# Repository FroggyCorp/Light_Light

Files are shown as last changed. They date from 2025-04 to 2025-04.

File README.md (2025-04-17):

# Light Light
It's a small PCB game with actually 2 games :

https://www.youtube.com/video/Cth2Q4qN7tQ/

https://www.youtube.com/video/z0U1Xu2ibLQ/

## The game

### How it work
Button 9 disable sound (horrible, i know)
Button 1 & 2 start game 1 or 2
All Button Player 1 & 2 at same time at the beggining reset highscore (little bit hard)

### Configuration
In light_light_func.h duree_jeu change the timeout of game1 2 = 20s
You can also change how many led will light at same time on game 1 with Jeu1_nombre_led_joueur_actif

### Game 1
You will have 4 LED, press button with led on as fast as you can until timeout of the game.

### Game 2
The program will add one led every x secondes, going faster and faster. It end when all the led are on for the two players.

## Game Board

Actually there is only dev board, which don't change so much. You can remove external connector to gain some place and make a smaller PCB.
It use an Attiny1604 & HT16K33A as it was the cheapest price and easy to use. Version with 75HC595 & 74HC595 may be a little bit cheaper but more difficult to make.
For Attiny1604, all reference on how to use it are[here]([https://pages.github.com/](https://github.com/SpenceKonde/AVR-Guidance/blob/master/UPDI/jtag2updi.md)) for UDPI & [here](https://github.com/SpenceKonde/megaTinyCore)
Thanks to [SpenceKonde](https://github.com/SpenceKonde) for his huge great work.

### Get notice
I use v1.1, v1.2 have some change and should work without problem.

### Information about the board
The board have 2 footprint for microphone, you need to get a passive one.
There are 2 foorprint for button + LED. One is cheap with standard 6x6mm tactil switch and 5730 LED, the other one use more expensive set with tactil switch & led in same package. You can take with [cap](https://www.lcsc.com/product-detail/Tactile-Switches_ROCPU-Switches-TPB01-101L1W_C2762125.html) or without and take that type of [cap] (https://www.lcsc.com/product-detail/Switch-Accessories-Caps_Khon-SC804AF1_C45359438.html). Be aware that some button + LED have cathode/anode at different position which will not work.
With 5730 LED, i recommend 5Kohm for R77 to R88 and 330ohm for the others.
You could also change the R for green LED.

### v1.2 :
- Correction Bug with Led J2 6-7-8-9
- Mutualising R for button
- Double footprint for microphone
- Change mounting hole
- Smaller PCB
- Add 5x220Ohm resistor to trick external battery cut off

## Small box

You can find .stl and FreeCad file inside FreeCad dir, as well as the PCB, i didn't try that version.

# Licence
Copyright (c) 2025 Froggy / FroggyCorp.

Do what you want with it until it's not money.

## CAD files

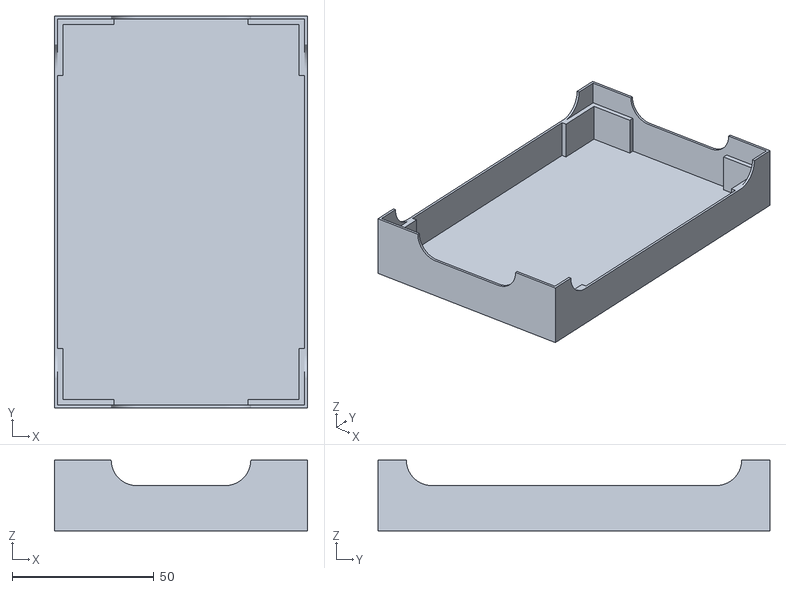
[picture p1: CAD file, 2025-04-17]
FreeCAD/Top - Dev Board v1.2.stl
89.2 x 138.2 x 25.0

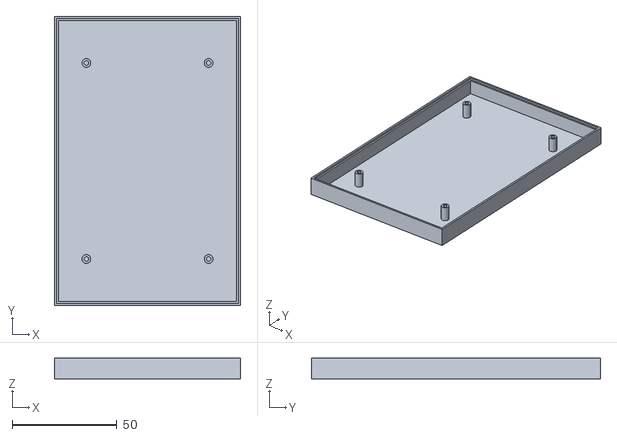
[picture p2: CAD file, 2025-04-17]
FreeCAD/Bottom - Dev Board v1.2.stl
89.0 x 138.0 x 10.0

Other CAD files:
FreeCAD/Boitier - Dev Board v1.2.FCStd

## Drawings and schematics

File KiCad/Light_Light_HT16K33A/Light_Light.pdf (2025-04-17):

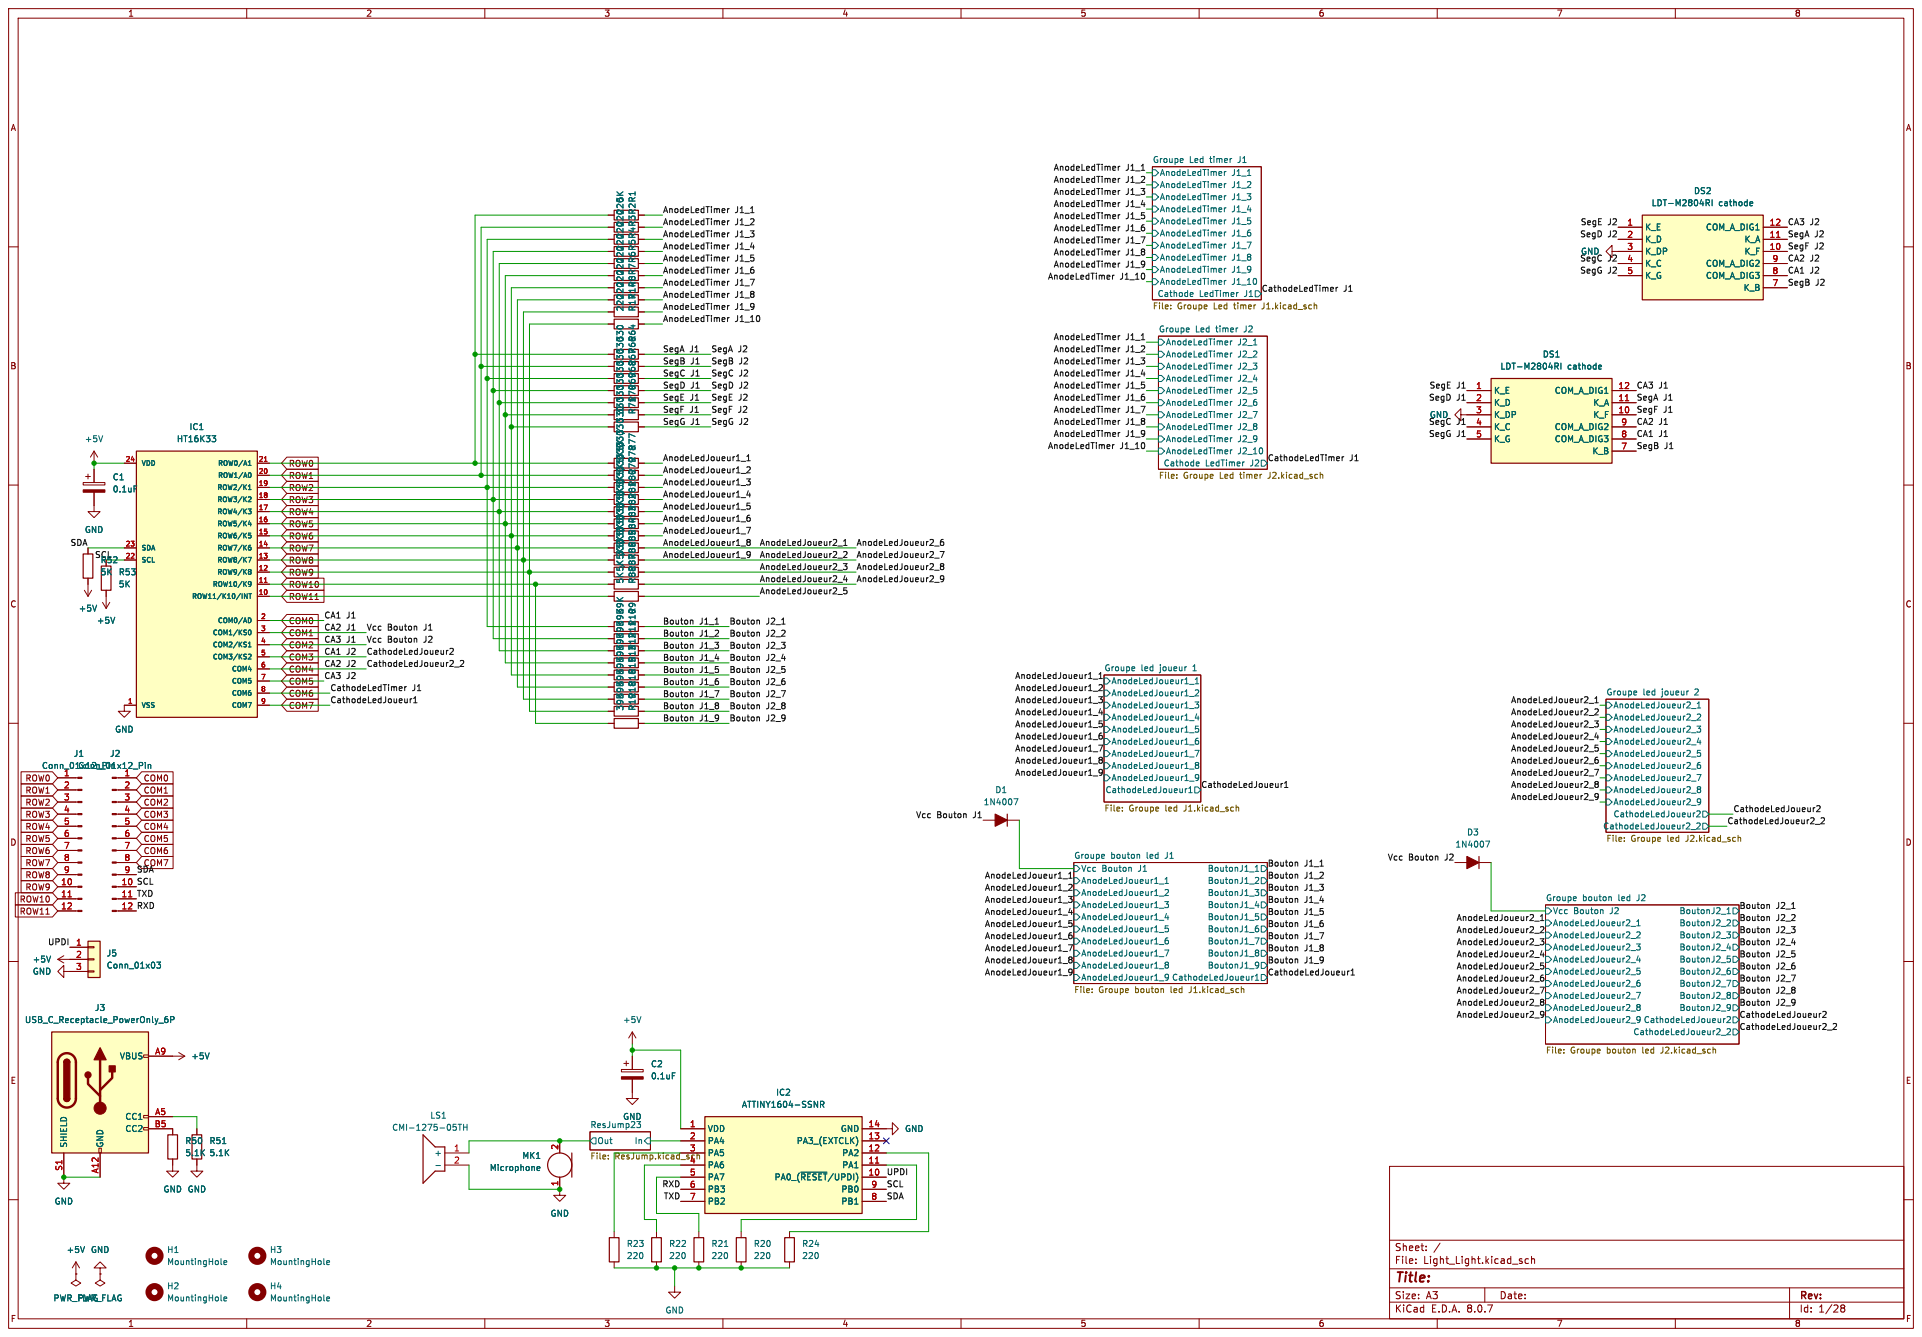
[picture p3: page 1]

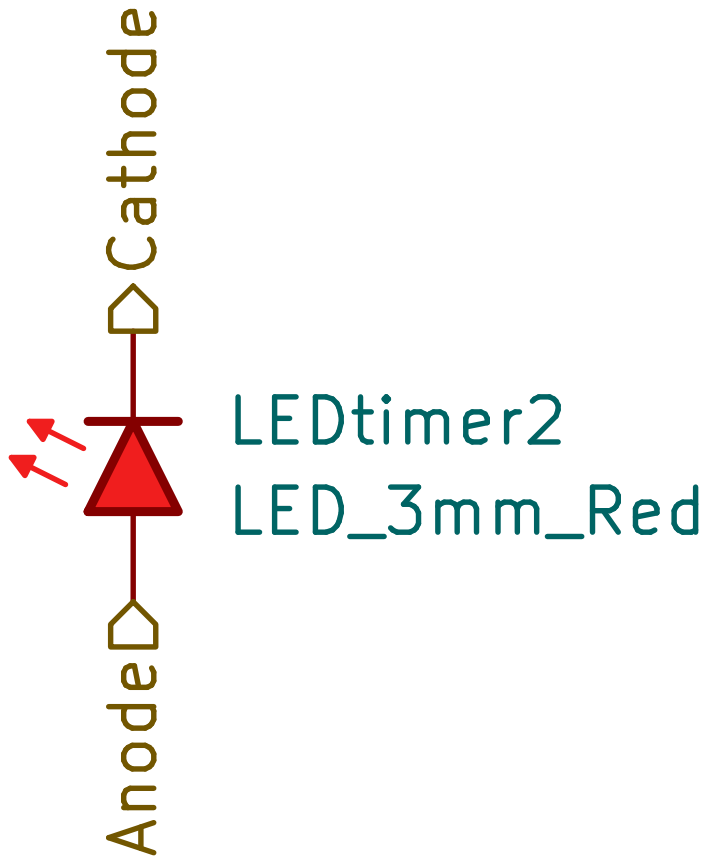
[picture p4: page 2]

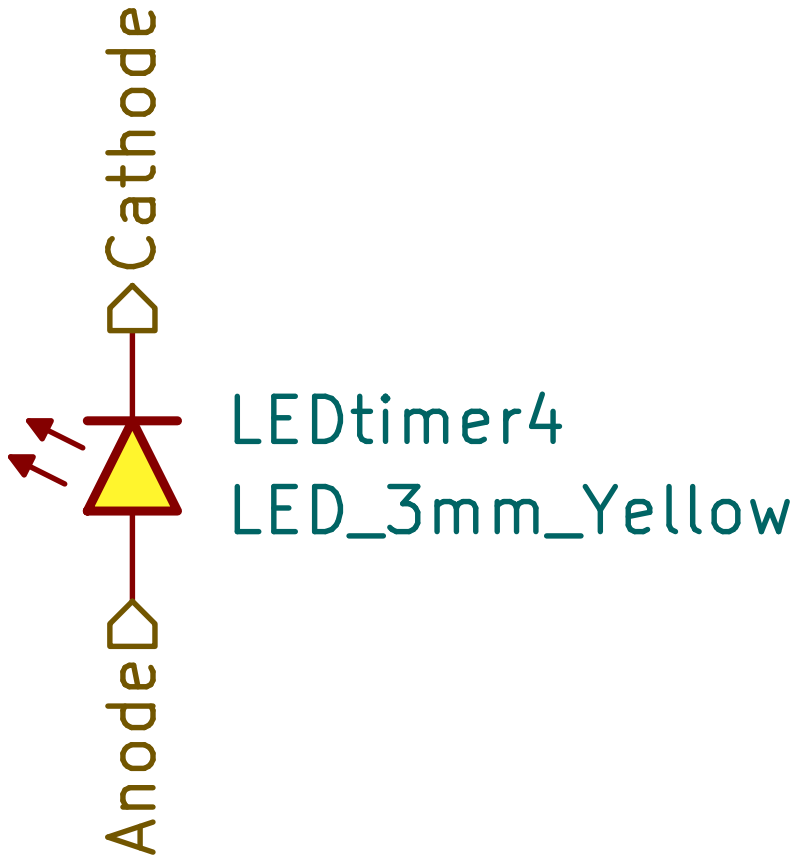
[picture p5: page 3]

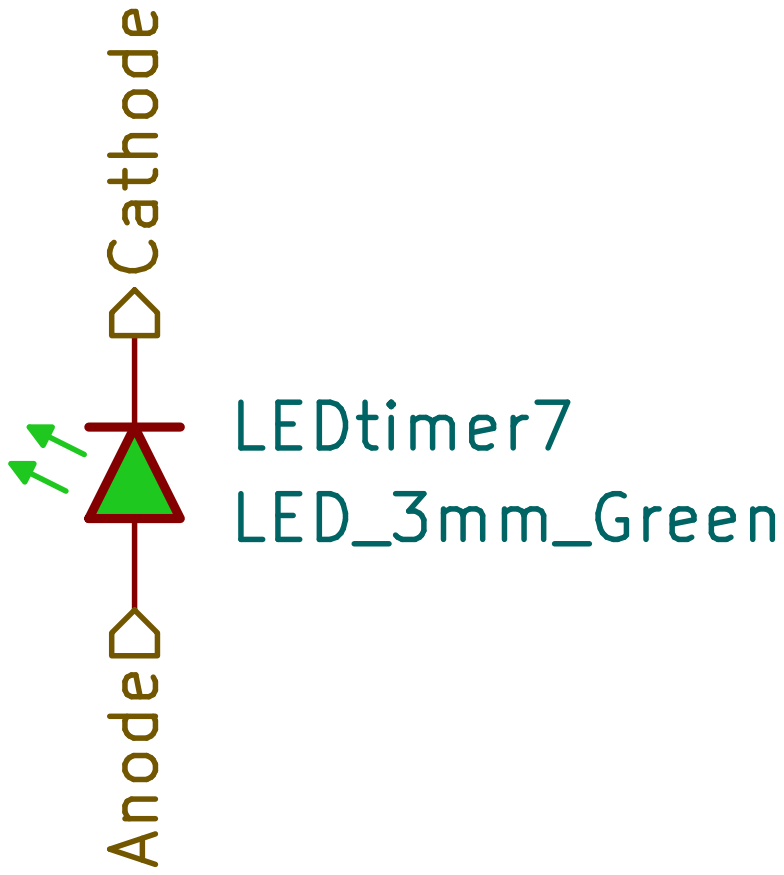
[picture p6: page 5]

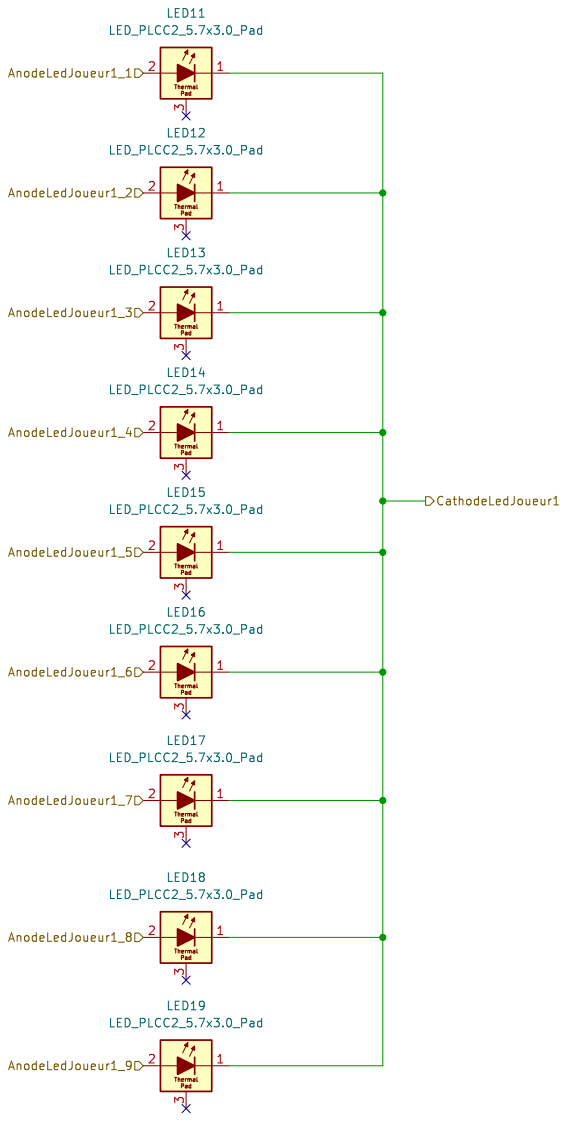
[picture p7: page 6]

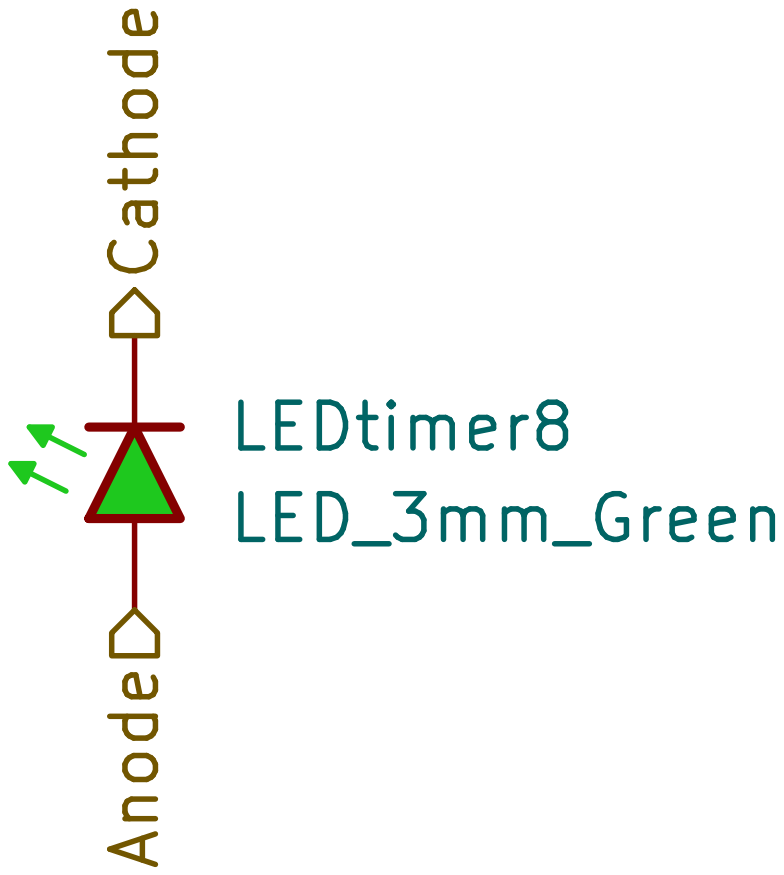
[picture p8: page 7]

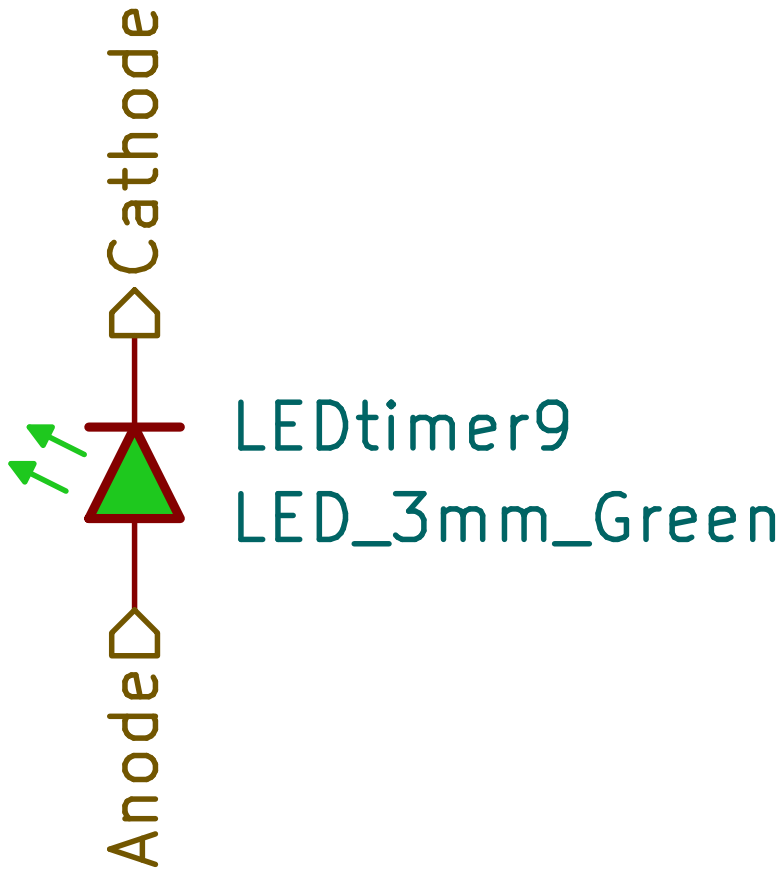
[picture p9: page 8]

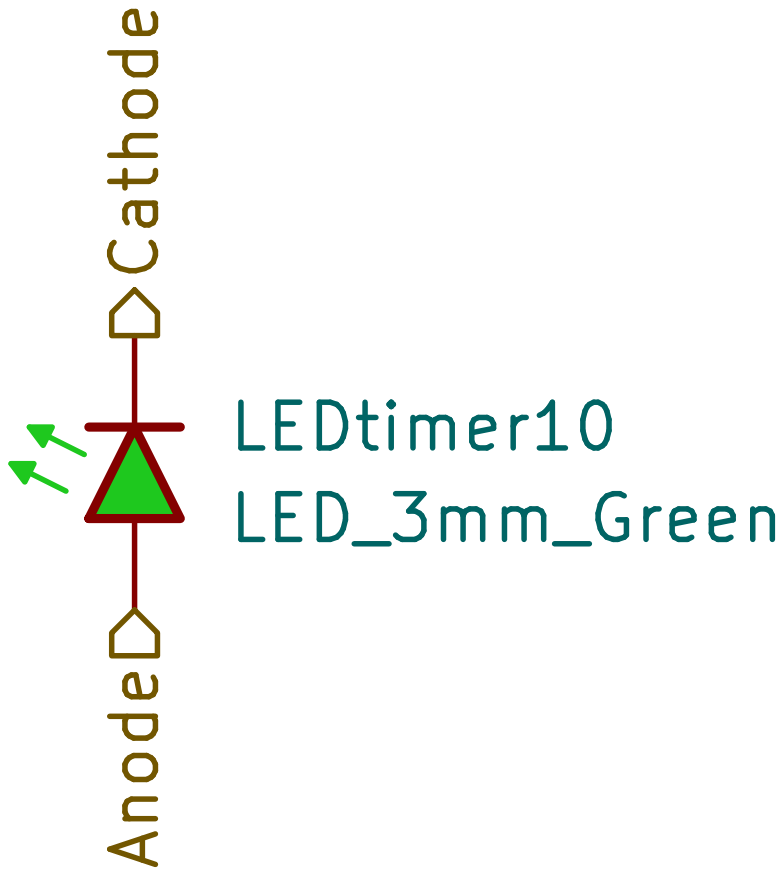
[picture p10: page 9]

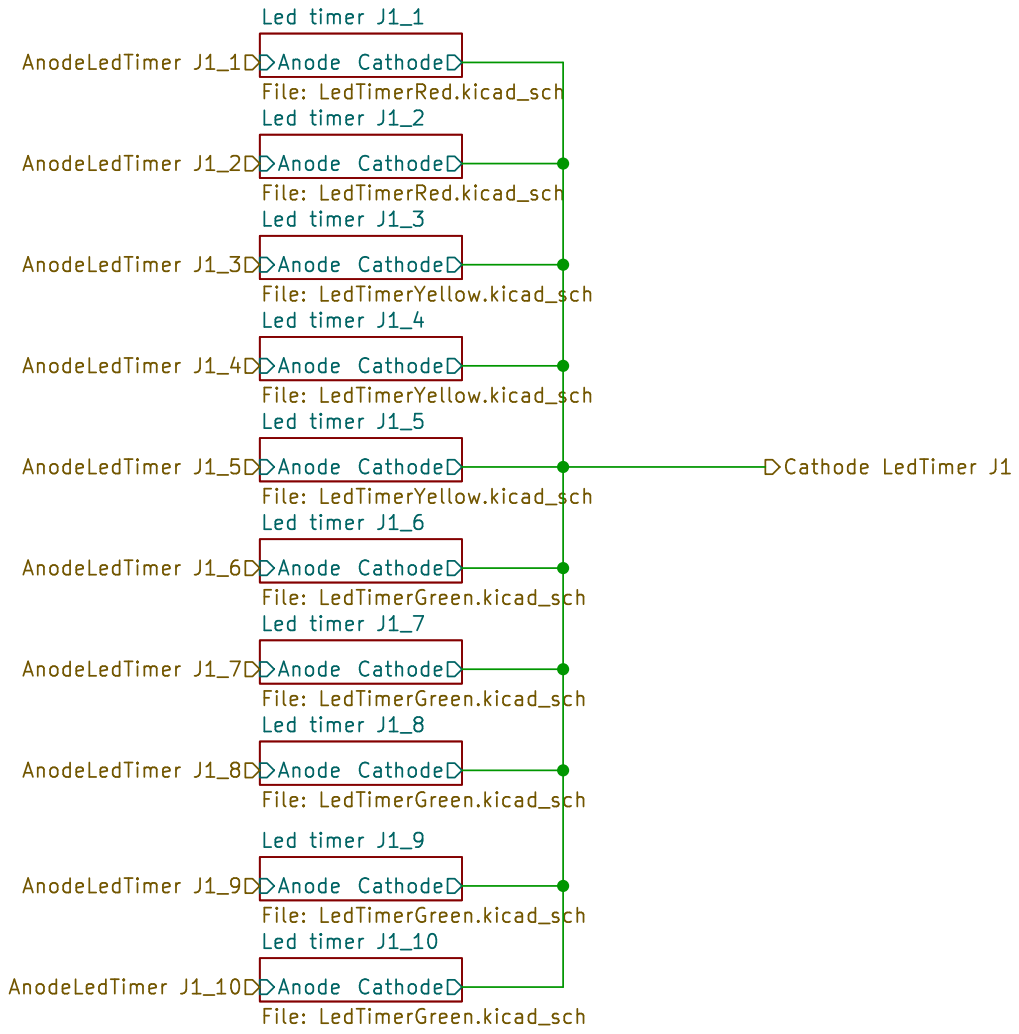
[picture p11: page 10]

Led timer J1_1 File: LedTimerRed.kicad_sch Anode Cathode

Led timer J1_2 File: LedTimerRed.kicad_sch Anode Cathode

Led timer J1_5 File: LedTimerYellow.kicad_sch Anode Cathode

Led timer J1_3 File: LedTimerYellow.kicad_sch Anode Cathode

Led timer J1_4 File: LedTimerYellow.kicad_sch Anode Cathode

Led timer J1_7 File: LedTimerGreen.kicad_sch Anode Cathode

Led timer J1_6 File: LedTimerGreen.kicad_sch Anode Cathode

Led timer J1_9 File: LedTimerGreen.kicad_sch Anode Cathode

Led timer J1_10 File: LedTimerGreen.kicad_sch Anode Cathode

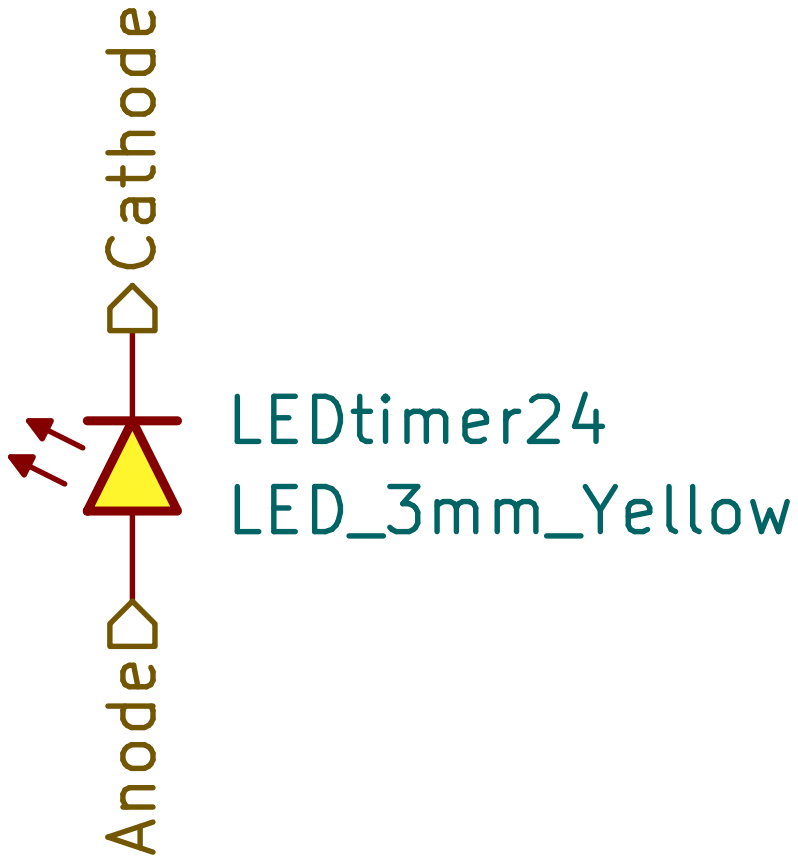
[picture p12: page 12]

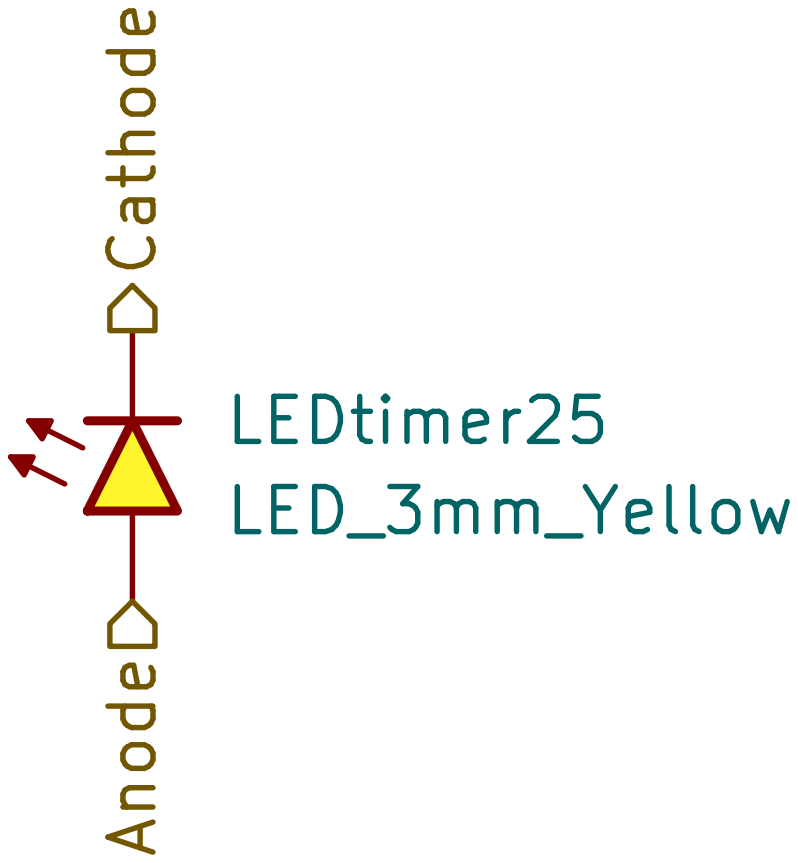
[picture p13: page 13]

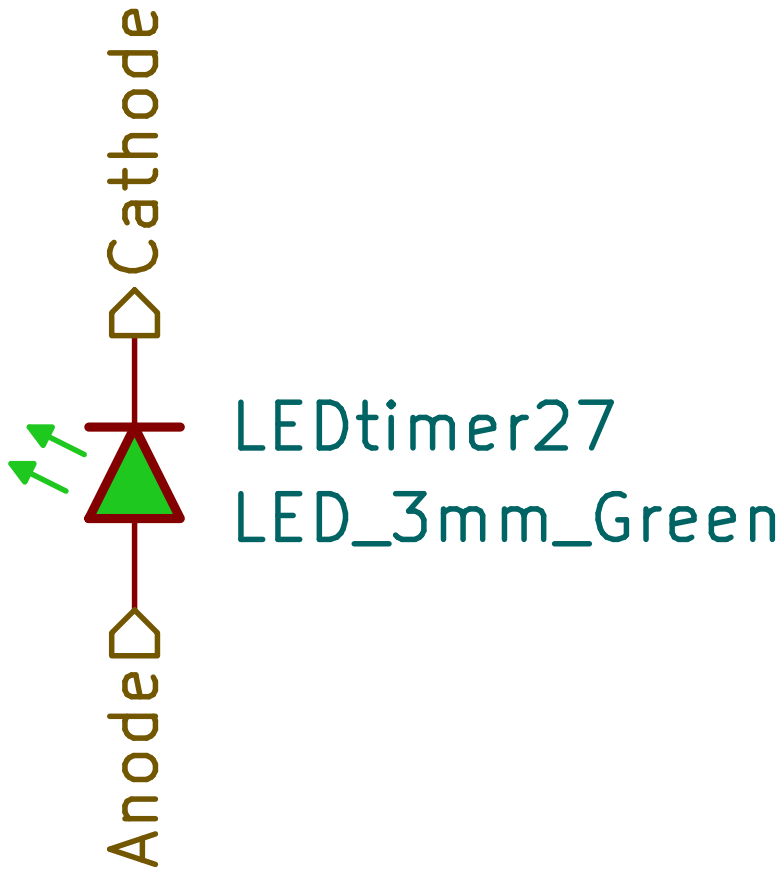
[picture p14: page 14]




Id: 40/28 Title: File: ResJump.kicad_sch Sheet: /ResJump23/










Led timer J2_1 File: LedTimerRed.kicad_sch Anode Cathode
Led timer J2_2 File: LedTimerRed.kicad_sch Anode Cathode

Led timer J2_6 File: LedTimerGreen.kicad_sch Anode Cathode

Led timer J2_4 File: LedTimerYellow.kicad_sch Anode Cathode

Led timer J2_3 File: LedTimerYellow.kicad_sch Anode Cathode

Led timer J2_5 File: LedTimerYellow.kicad_sch Anode Cathode

Led timer J2_9 File: LedTimerGreen.kicad_sch Anode Cathode

Led timer J2_8 File: LedTimerGreen.kicad_sch Anode Cathode

Led timer J2_10 File: LedTimerGreen.kicad_sch Anode Cathode

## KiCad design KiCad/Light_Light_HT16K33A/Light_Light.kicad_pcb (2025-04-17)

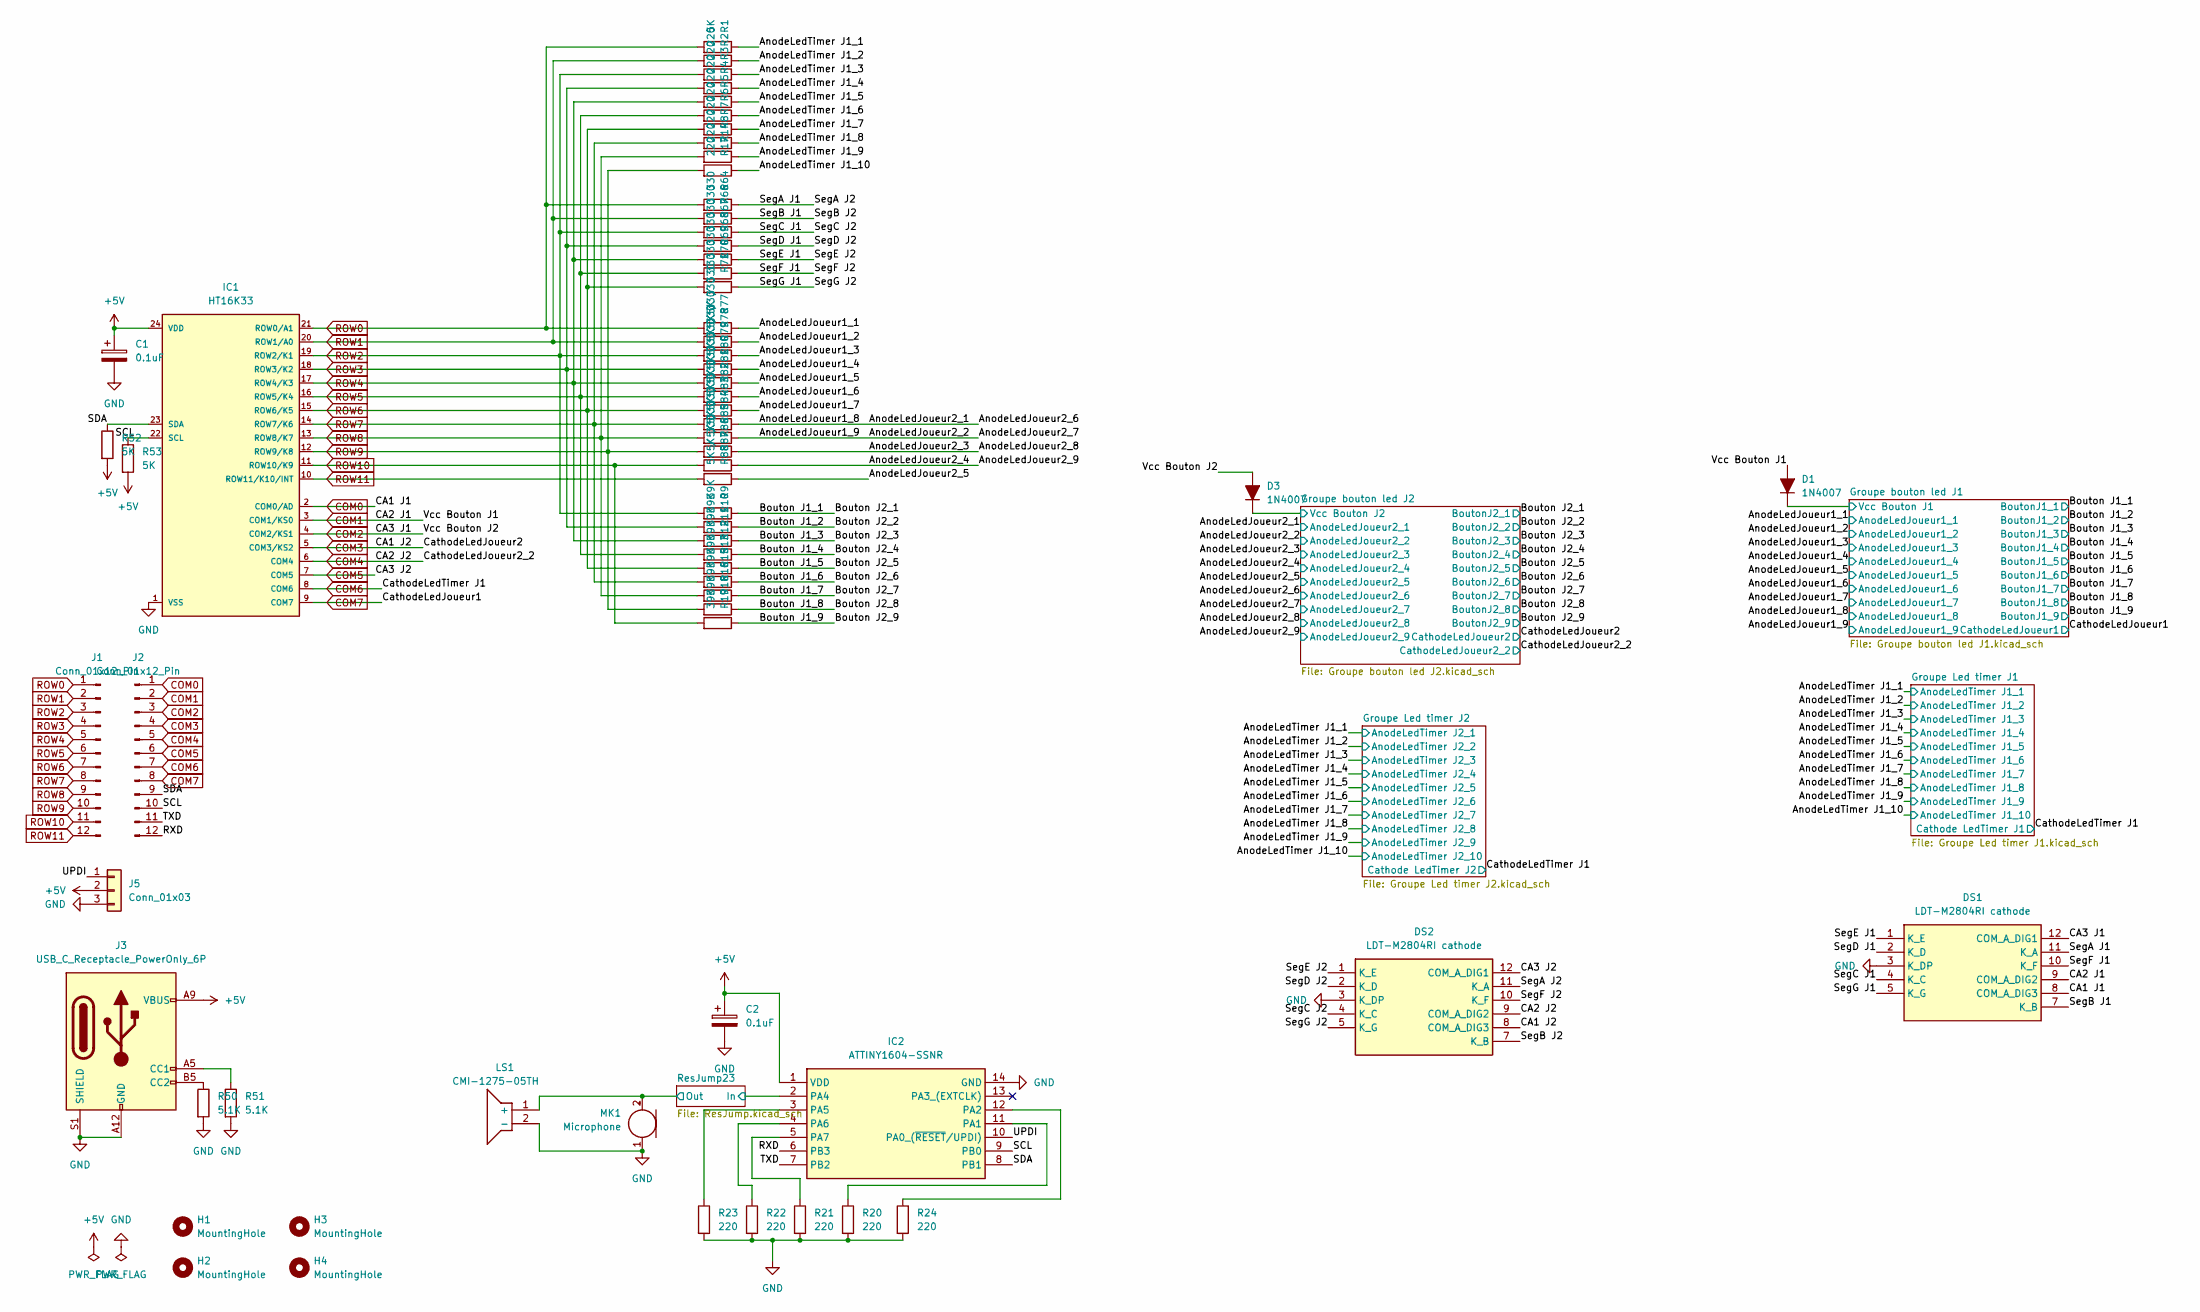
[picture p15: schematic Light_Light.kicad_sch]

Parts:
C1, C2: 0.1uF; C_0805_2012Metric_Pad1.15x1.40mm_HandSolder
D1, D3: 1N4007; D_DO-214AC_SMA; LCSC Part # C232439
DS1, DS2: LDT-M2804RI cathode; LDTM2804RI; Mouser Part Number 696-LDT-M2804RI
H1, H2, H3, H4: MountingHole; MountingHole_2.2mm_M2
IC1: HT16K33; LCSC Part # C5444736
IC2: ATTINY1604-SSNR; SOIC127P600X175-14N; Mouser Part Number 579-ATTINY1604-SSNR
J1, J2: Conn_01x12_Pin; PinHeader_1x12_P2.54mm_Vertical
J3: USB_C_Receptacle_PowerOnly_6P; USB_C_Receptacle_GCT_USB4125-xx-x_6P_TopMnt_Horizontal; LCSC Part # C668623
J5: Conn_01x03; PinHeader_1x03_P2.54mm_Horizontal; Part Number 1-0301FBV0T
LS1: CMI-1275-05TH; CMI127505TH; Mouser Part Number 179-CMI-1275-05TH
MK1: Microphone; POM-2244P-C3310-2-R; LCSC Part # C233957
R1, R52, R53: 5K; R_0805_2012Metric_Pad1.20x1.40mm_HandSolder
R2, R3, R4, R5, R6, R7, R8, R14, R17, R20, R21, R22, R23, R24: 220; R_0805_2012Metric_Pad1.20x1.40mm_HandSolder
R9, R10, R11, R12, R13, R15, R16, R18, R19: 39K; R_0805_2012Metric_Pad1.20x1.40mm_HandSolder
R50, R51: 5.1K; R_0805_2012Metric_Pad1.20x1.40mm_HandSolder
R64, R66, R67, R68, R69, R70, R71: 330; R_0805_2012Metric_Pad1.20x1.40mm_HandSolder
R77, R78, R79, R80, R81, R82, R83, R84, R85, R86, R87, R88: 5K / 330; R_0805_2012Metric_Pad1.20x1.40mm_HandSolder

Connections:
+5V: C1.1, C2.1, IC1.24 (VDD), IC2.1 (VDD), J3.A9 (VBUS), J3.B9 (VBUS), J5.2, R52.2, R53.2
/AnodeLedJoueur1_1: R77.1; also elsewhere on the board
/AnodeLedJoueur1_2: R78.1; also elsewhere on the board
/AnodeLedJoueur1_3: R79.1; also elsewhere on the board
/AnodeLedJoueur1_4: R80.1; also elsewhere on the board
/AnodeLedJoueur1_5: R81.1; also elsewhere on the board
/AnodeLedJoueur1_6: R82.1; also elsewhere on the board
/AnodeLedJoueur1_7: R83.1; also elsewhere on the board
/AnodeLedJoueur1_8: R84.1; also elsewhere on the board
/AnodeLedJoueur1_9: R85.1; also elsewhere on the board
/AnodeLedJoueur2_3: R86.1; also elsewhere on the board
/AnodeLedJoueur2_4: R87.1; also elsewhere on the board
/AnodeLedJoueur2_5: R88.1; also elsewhere on the board
/AnodeLedTimer J1_1: R1.1; also elsewhere on the board
/AnodeLedTimer J1_2: R2.1; also elsewhere on the board
/AnodeLedTimer J1_3: R3.1; also elsewhere on the board
/AnodeLedTimer J1_4: R4.1; also elsewhere on the board
/AnodeLedTimer J1_5: R5.1; also elsewhere on the board
/AnodeLedTimer J1_6: R6.1; also elsewhere on the board
/AnodeLedTimer J1_7: R7.1; also elsewhere on the board
/AnodeLedTimer J1_8: R8.1; also elsewhere on the board
/AnodeLedTimer J1_9: R14.1; also elsewhere on the board
/AnodeLedTimer J1_10: R17.1; also elsewhere on the board
/Bouton J1_1: R9.1; also elsewhere on the board
/Bouton J1_2: R10.1; also elsewhere on the board
/Bouton J1_3: R11.1; also elsewhere on the board
/Bouton J1_4: R12.1; also elsewhere on the board
/Bouton J1_5: R13.1; also elsewhere on the board
/Bouton J1_6: R15.1; also elsewhere on the board
/Bouton J1_7: R16.1; also elsewhere on the board
/Bouton J1_8: R18.1; also elsewhere on the board
/Bouton J1_9: R19.1; also elsewhere on the board
/Groupe bouton led J1/Vcc Bouton J1: D1.1 (K); also elsewhere on the board
/Groupe bouton led J2/Vcc Bouton J2: D3.1 (K); also elsewhere on the board
/RXD: IC2.6 (PB3), J2.12
/ResJump23/In: IC2.2 (PA4); also elsewhere on the board
/ResJump23/Out: LS1.1 (+), MK1.2 (+); also elsewhere on the board
/SCL: IC1.22 (SCL), IC2.9 (PB0), J2.10, R53.1
/SDA: IC1.23 (SDA), IC2.8 (PB1), J2.9, R52.1
/SegA J1: DS1.11 (K_A), DS2.11 (K_A), R64.1
/SegB J1: DS1.7 (K_B), DS2.7 (K_B), R66.1
/SegC J1: DS1.4 (K_C), DS2.4 (K_C), R67.1
/SegD J1: DS1.2 (K_D), DS2.2 (K_D), R68.1
/SegE J1: DS1.1 (K_E), DS2.1 (K_E), R69.1
/SegF J1: DS1.10 (K_F), DS2.10 (K_F), R70.1
/SegG J1: DS1.5 (K_G), DS2.5 (K_G), R71.1
/TXD: IC2.7 (PB2), J2.11
/UPDI: IC2.10 (PA0_(~RESET/UPDI)), J5.1
COM0: DS1.8 (COM_A_DIG3), IC1.2 (COM0/AD), J2.1
COM1: D1.2 (A), DS1.9 (COM_A_DIG2), IC1.3 (COM1/KS0), J2.2
COM2: D3.2 (A), DS1.12 (COM_A_DIG1), IC1.4 (COM2/KS1), J2.3
COM3: DS2.8 (COM_A_DIG3), IC1.5 (COM3/KS2), J2.4; also elsewhere on the board
COM4: DS2.9 (COM_A_DIG2), IC1.6 (COM4), J2.5; also elsewhere on the board
COM5: DS2.12 (COM_A_DIG1), IC1.7 (COM5), J2.6
COM6: IC1.8 (COM6), J2.7; also elsewhere on the board
COM7: IC1.9 (COM7), J2.8; also elsewhere on the board
GND: C1.2, C2.2, DS1.3 (K_DP), DS2.3 (K_DP), IC1.1 (VSS), IC2.14 (GND), J3.A12 (GND), J3.B12 (GND), J3.S1 (SHIELD), J5.3, LS1.2 (-), MK1.1 (-), R20.2, R21.2, R22.2, R23.2, R24.2, R50.2, R51.2
unnamed: IC2.11 (PA1), R20.1
unnamed: IC2.12 (PA2), R24.1
unnamed: IC2.3 (PA5), R23.1
unnamed: IC2.4 (PA6), R22.1
unnamed: IC2.5 (PA7), R21.1
unnamed: J3.A5 (CC1), R51.1
unnamed: J3.B5 (CC2), R50.1
ROW0: IC1.21 (ROW0/A1), J1.1, R1.2, R64.2, R77.2
ROW1: IC1.20 (ROW1/A0), J1.2, R2.2, R66.2, R78.2
ROW2: IC1.19 (ROW2/K1), J1.3, R3.2, R9.2, R67.2, R79.2
ROW3: IC1.18 (ROW3/K2), J1.4, R4.2, R10.2, R68.2, R80.2
ROW4: IC1.17 (ROW4/K3), J1.5, R5.2, R11.2, R69.2, R81.2
ROW5: IC1.16 (ROW5/K4), J1.6, R6.2, R12.2, R70.2, R82.2
ROW6: IC1.15 (ROW6/K5), J1.7, R7.2, R13.2, R71.2, R83.2
ROW7: IC1.14 (ROW7/K6), J1.8, R8.2, R15.2, R84.2
ROW8: IC1.13 (ROW8/K7), J1.9, R14.2, R16.2, R85.2
ROW9: IC1.12 (ROW9/K8), J1.10, R17.2, R18.2, R86.2
ROW10: IC1.11 (ROW10/K9), J1.11, R19.2, R87.2
ROW11: IC1.10 (ROW11/K10/INT), J1.12, R88.2

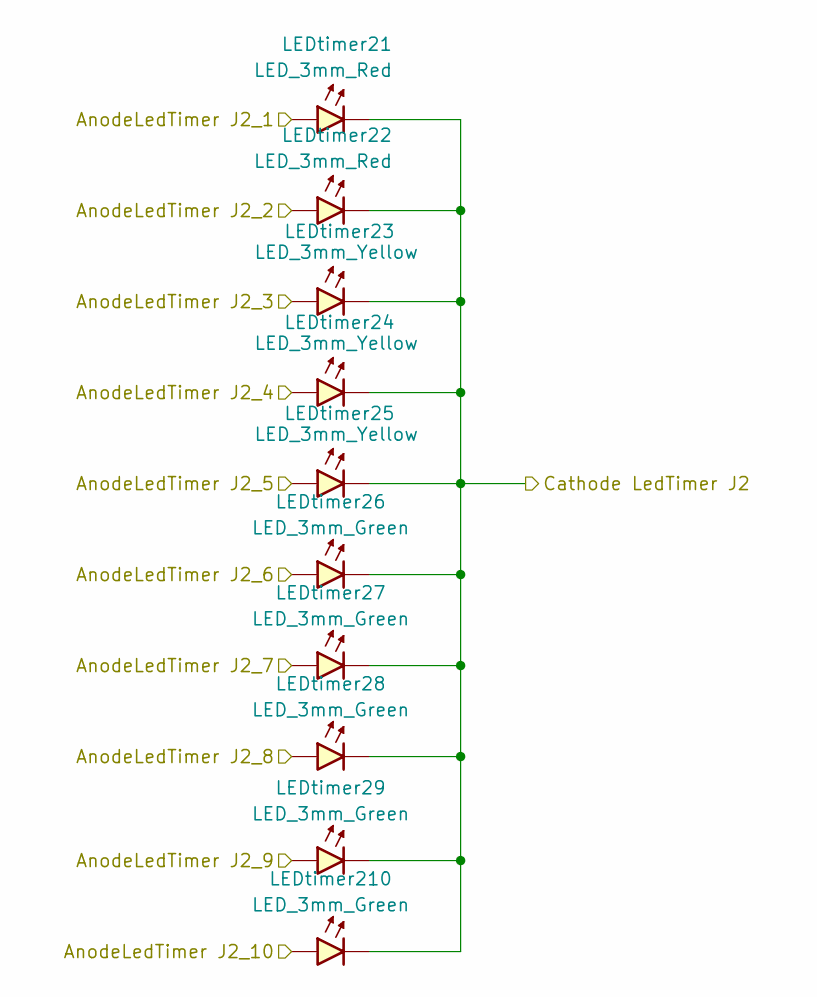
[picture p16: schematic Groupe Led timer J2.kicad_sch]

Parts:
LEDtimer21, LEDtimer22: LED_3mm_Red; LED_D3.0mm; LCSC Part # C84774
LEDtimer23, LEDtimer24, LEDtimer25: LED_3mm_Yellow; LED_D3.0mm; LCSC Part # C2895472
LEDtimer26, LEDtimer27, LEDtimer28, LEDtimer29, LEDtimer210: LED_3mm_Green; LED_D3.0mm; LCSC Part # C5907154

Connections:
/AnodeLedTimer J1_1: LEDtimer21.2 (A); also elsewhere on the board
/AnodeLedTimer J1_2: LEDtimer22.2 (A); also elsewhere on the board
/AnodeLedTimer J1_3: LEDtimer23.2 (A); also elsewhere on the board
/AnodeLedTimer J1_4: LEDtimer24.2 (A); also elsewhere on the board
/AnodeLedTimer J1_5: LEDtimer25.2 (A); also elsewhere on the board
/AnodeLedTimer J1_6: LEDtimer26.2 (A); also elsewhere on the board
/AnodeLedTimer J1_7: LEDtimer27.2 (A); also elsewhere on the board
/AnodeLedTimer J1_8: LEDtimer28.2 (A); also elsewhere on the board
/AnodeLedTimer J1_9: LEDtimer29.2 (A); also elsewhere on the board
/AnodeLedTimer J1_10: LEDtimer210.2 (A); also elsewhere on the board
COM6: LEDtimer21.1 (K), LEDtimer22.1 (K), LEDtimer23.1 (K), LEDtimer24.1 (K), LEDtimer25.1 (K), LEDtimer26.1 (K), LEDtimer27.1 (K), LEDtimer28.1 (K), LEDtimer29.1 (K), LEDtimer210.1 (K); also elsewhere on the board

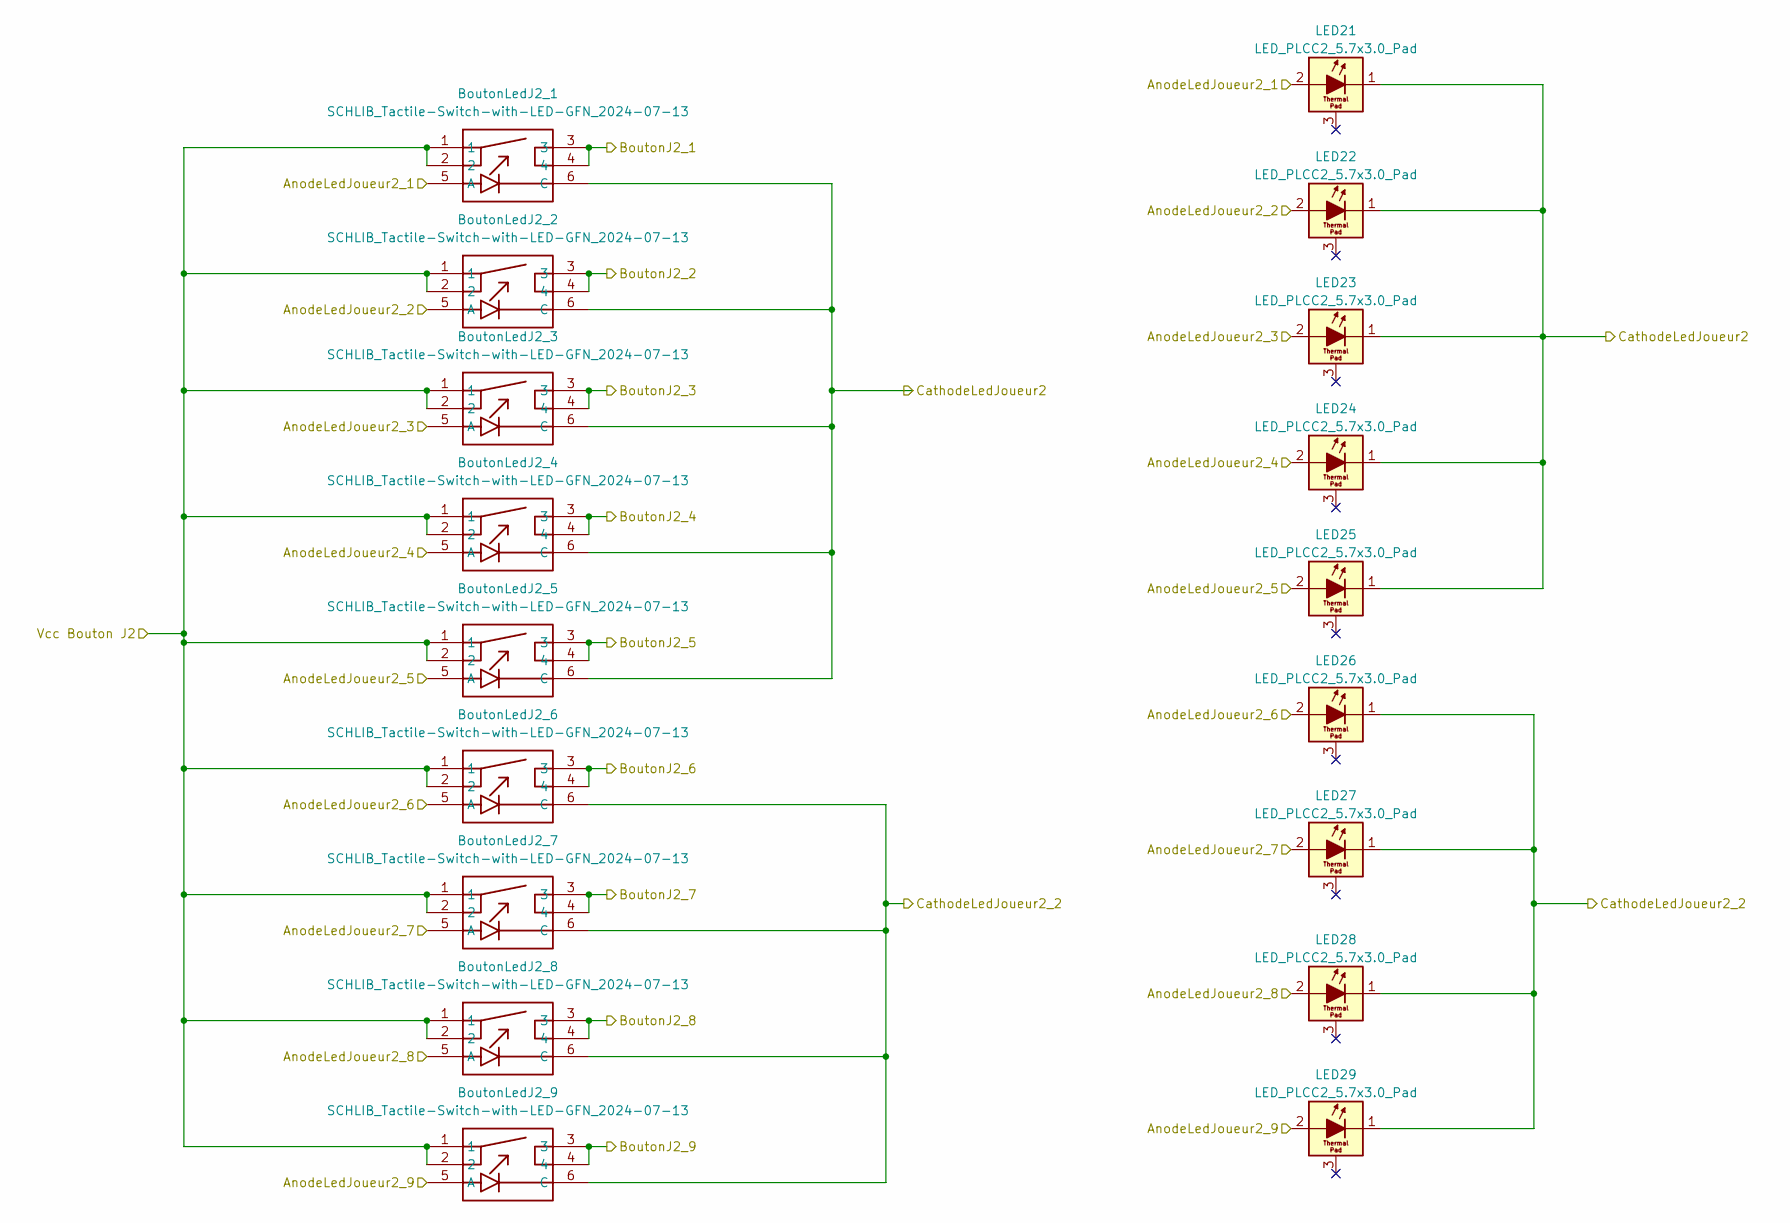
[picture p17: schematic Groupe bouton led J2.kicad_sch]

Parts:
BoutonLedJ2_1, BoutonLedJ2_2, BoutonLedJ2_3, BoutonLedJ2_4, BoutonLedJ2_5, BoutonLedJ2_6, BoutonLedJ2_7, BoutonLedJ2_8, BoutonLedJ2_9: SCHLIB_Tactile-Switch-with-LED-GFN_2024-07-13; 6MM SWITCH WITH LED GFN; Manufacturer Part New SchematicLib; LCSC Part # C354964
LED21, LED22, LED23, LED24, LED25, LED26, LED27, LED28, LED29: LED_PLCC2_5.7x3.0_Pad; LED_Yuji_5730

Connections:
/AnodeLedJoueur1_8: BoutonLedJ2_1.5 (A), BoutonLedJ2_6.5 (A), LED21.2 (A), LED26.2 (A); also elsewhere on the board
/AnodeLedJoueur1_9: BoutonLedJ2_2.5 (A), BoutonLedJ2_7.5 (A), LED22.2 (A), LED27.2 (A); also elsewhere on the board
/AnodeLedJoueur2_3: BoutonLedJ2_3.5 (A), BoutonLedJ2_8.5 (A), LED23.2 (A), LED28.2 (A); also elsewhere on the board
/AnodeLedJoueur2_4: BoutonLedJ2_4.5 (A), BoutonLedJ2_9.5 (A), LED24.2 (A), LED29.2 (A); also elsewhere on the board
/AnodeLedJoueur2_5: BoutonLedJ2_5.5 (A), LED25.2 (A); also elsewhere on the board
/Bouton J1_1: BoutonLedJ2_1.3, BoutonLedJ2_1.4; also elsewhere on the board
/Bouton J1_2: BoutonLedJ2_2.3, BoutonLedJ2_2.4; also elsewhere on the board
/Bouton J1_3: BoutonLedJ2_3.3, BoutonLedJ2_3.4; also elsewhere on the board
/Bouton J1_4: BoutonLedJ2_4.3, BoutonLedJ2_4.4; also elsewhere on the board
/Bouton J1_5: BoutonLedJ2_5.3, BoutonLedJ2_5.4; also elsewhere on the board
/Bouton J1_6: BoutonLedJ2_6.3, BoutonLedJ2_6.4; also elsewhere on the board
/Bouton J1_7: BoutonLedJ2_7.3, BoutonLedJ2_7.4; also elsewhere on the board
/Bouton J1_8: BoutonLedJ2_8.3, BoutonLedJ2_8.4; also elsewhere on the board
/Bouton J1_9: BoutonLedJ2_9.3, BoutonLedJ2_9.4; also elsewhere on the board
/Groupe bouton led J2/Vcc Bouton J2: BoutonLedJ2_1.1, BoutonLedJ2_1.2, BoutonLedJ2_2.1, BoutonLedJ2_2.2, BoutonLedJ2_3.1, BoutonLedJ2_3.2, BoutonLedJ2_4.1, BoutonLedJ2_4.2, BoutonLedJ2_5.1, BoutonLedJ2_5.2, BoutonLedJ2_6.1, BoutonLedJ2_6.2, BoutonLedJ2_7.1, BoutonLedJ2_7.2, BoutonLedJ2_8.1, BoutonLedJ2_8.2, BoutonLedJ2_9.1, BoutonLedJ2_9.2; also elsewhere on the board
COM3: BoutonLedJ2_1.6 (C), BoutonLedJ2_2.6 (C), BoutonLedJ2_3.6 (C), BoutonLedJ2_4.6 (C), BoutonLedJ2_5.6 (C), LED21.1 (K), LED22.1 (K), LED23.1 (K), LED24.1 (K), LED25.1 (K); also elsewhere on the board
COM4: BoutonLedJ2_6.6 (C), BoutonLedJ2_7.6 (C), BoutonLedJ2_8.6 (C), BoutonLedJ2_9.6 (C), LED26.1 (K), LED27.1 (K), LED28.1 (K), LED29.1 (K); also elsewhere on the board

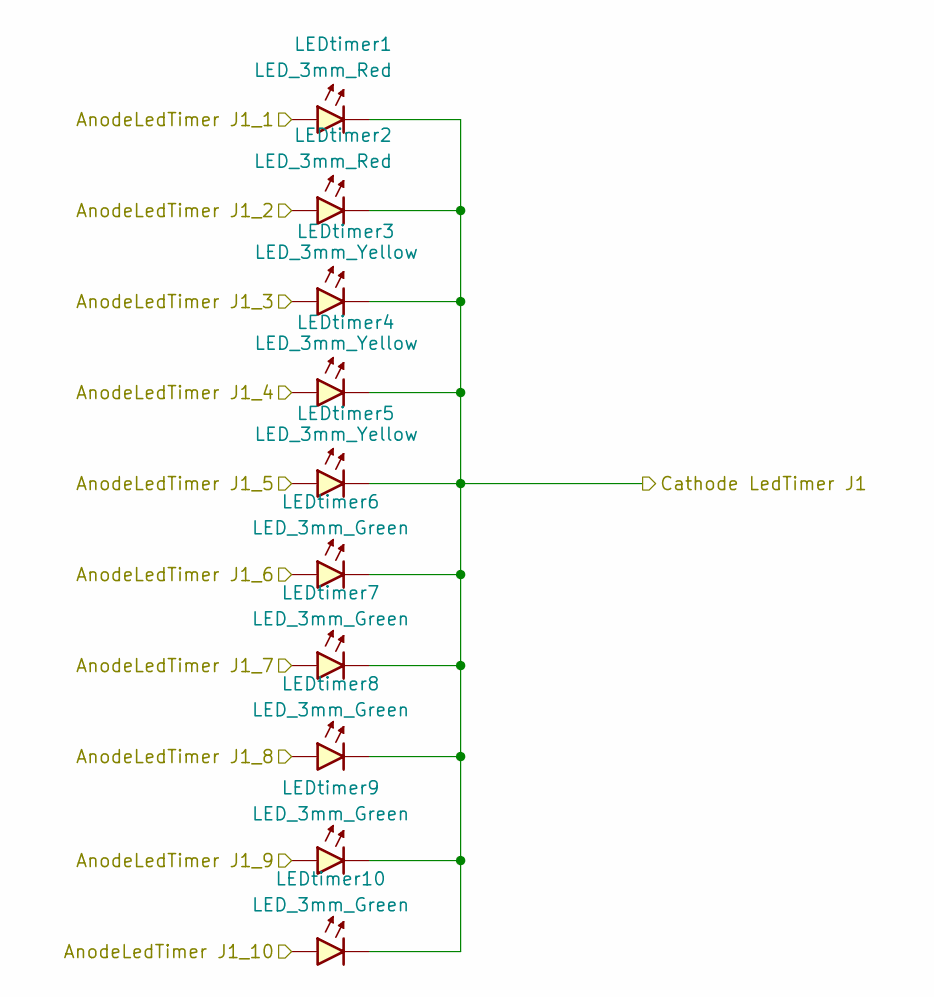
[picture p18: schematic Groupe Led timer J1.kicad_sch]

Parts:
LEDtimer1, LEDtimer2: LED_3mm_Red; LED_D3.0mm; LCSC Part # C84774
LEDtimer3, LEDtimer4, LEDtimer5: LED_3mm_Yellow; LED_D3.0mm; LCSC Part # C2895472
LEDtimer6, LEDtimer7, LEDtimer8, LEDtimer9, LEDtimer10: LED_3mm_Green; LED_D3.0mm; LCSC Part # C5907154

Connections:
/AnodeLedTimer J1_1: LEDtimer1.2 (A); also elsewhere on the board
/AnodeLedTimer J1_2: LEDtimer2.2 (A); also elsewhere on the board
/AnodeLedTimer J1_3: LEDtimer3.2 (A); also elsewhere on the board
/AnodeLedTimer J1_4: LEDtimer4.2 (A); also elsewhere on the board
/AnodeLedTimer J1_5: LEDtimer5.2 (A); also elsewhere on the board
/AnodeLedTimer J1_6: LEDtimer6.2 (A); also elsewhere on the board
/AnodeLedTimer J1_7: LEDtimer7.2 (A); also elsewhere on the board
/AnodeLedTimer J1_8: LEDtimer8.2 (A); also elsewhere on the board
/AnodeLedTimer J1_9: LEDtimer9.2 (A); also elsewhere on the board
/AnodeLedTimer J1_10: LEDtimer10.2 (A); also elsewhere on the board
COM6: LEDtimer1.1 (K), LEDtimer2.1 (K), LEDtimer3.1 (K), LEDtimer4.1 (K), LEDtimer5.1 (K), LEDtimer6.1 (K), LEDtimer7.1 (K), LEDtimer8.1 (K), LEDtimer9.1 (K), LEDtimer10.1 (K); also elsewhere on the board

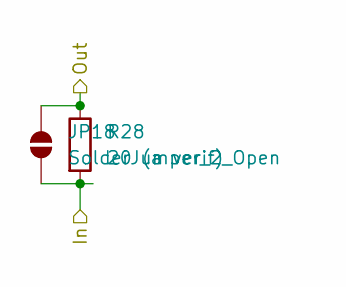
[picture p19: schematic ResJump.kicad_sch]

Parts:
JP18: SolderJumper_2_Open; SolderJumper-2_P1.3mm_Open_Pad1.0x1.5mm
R28: 20 (a verif); R_0805_2012Metric_Pad1.20x1.40mm_HandSolder

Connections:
/ResJump23/In: JP18.2 (B), R28.2; also elsewhere on the board
/ResJump23/Out: JP18.1 (A), R28.1; also elsewhere on the board

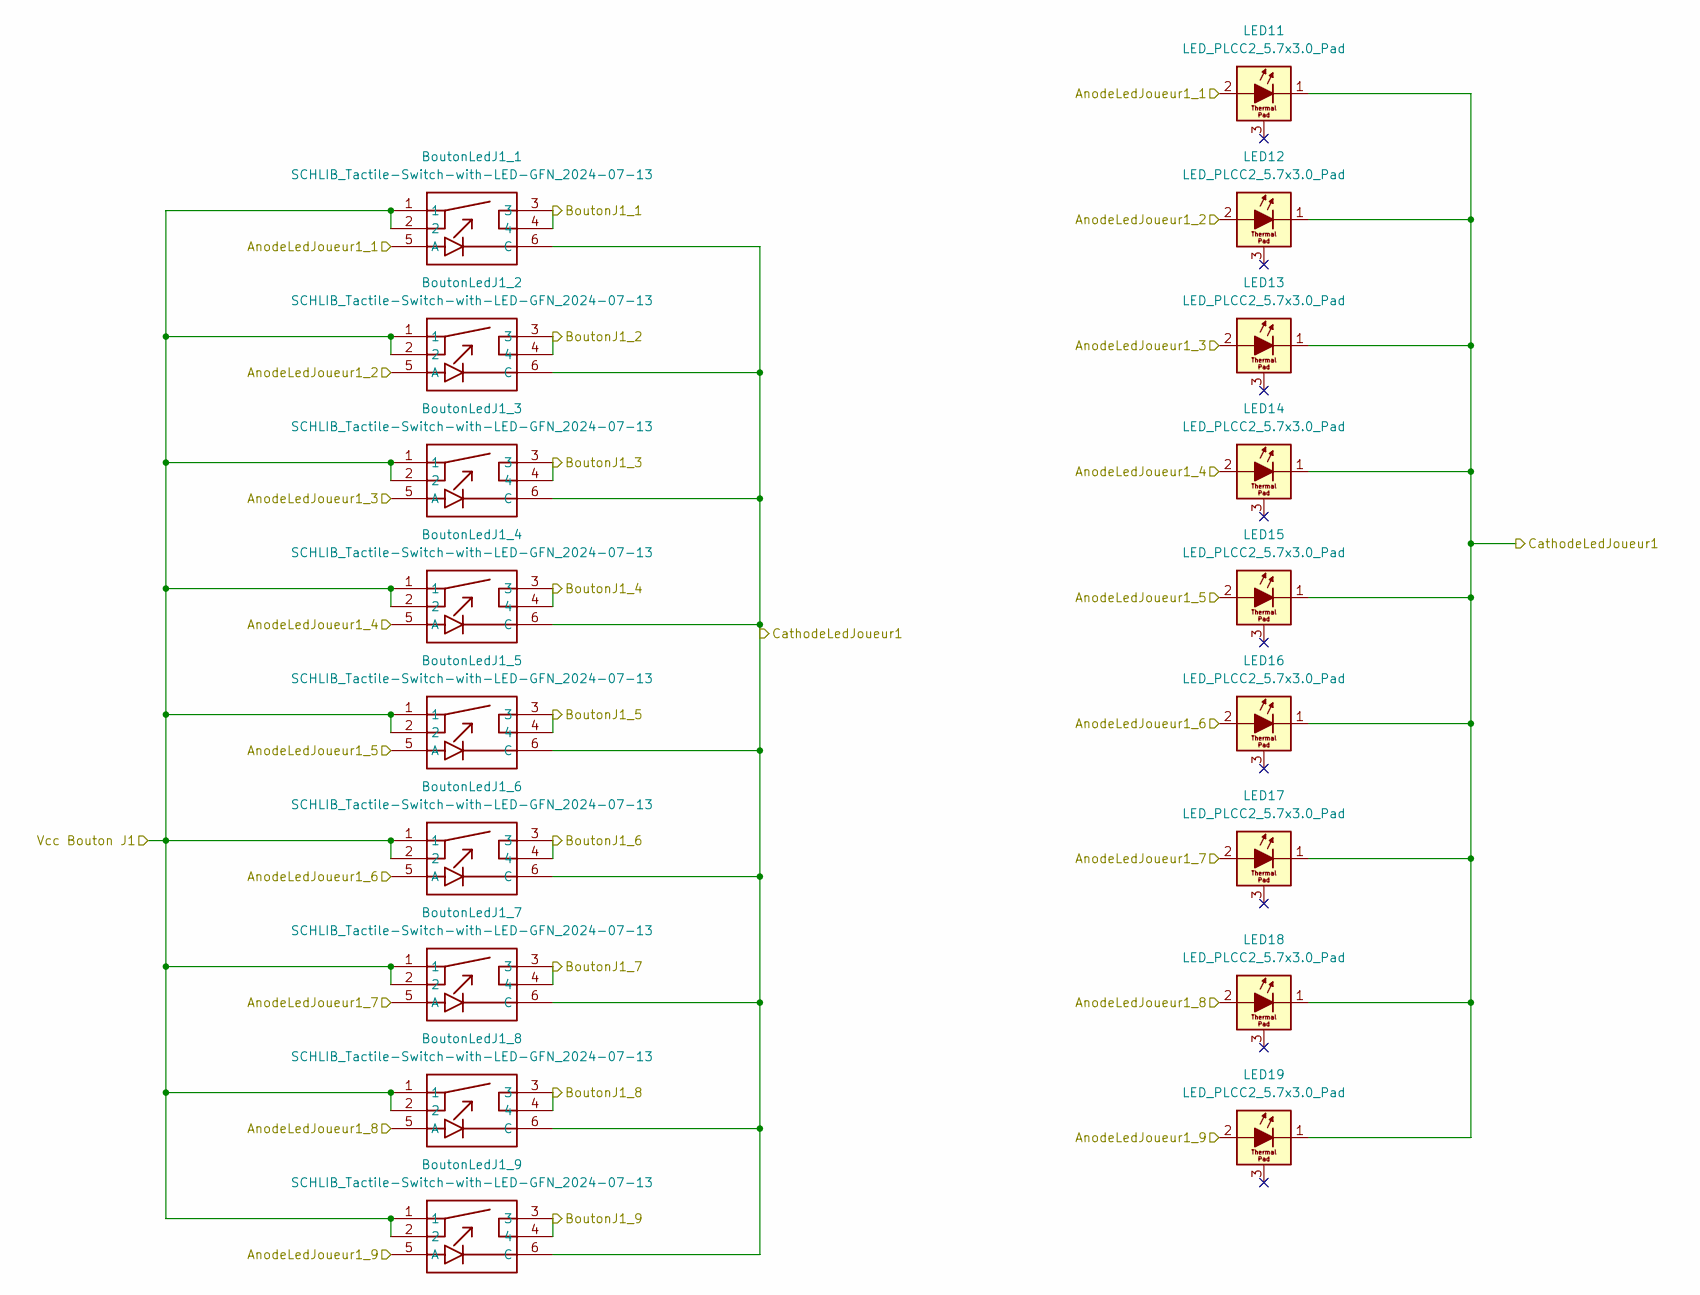
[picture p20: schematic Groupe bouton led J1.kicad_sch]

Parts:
BoutonLedJ1_1, BoutonLedJ1_2, BoutonLedJ1_3, BoutonLedJ1_4, BoutonLedJ1_5, BoutonLedJ1_6, BoutonLedJ1_7, BoutonLedJ1_8, BoutonLedJ1_9: SCHLIB_Tactile-Switch-with-LED-GFN_2024-07-13; 6MM SWITCH WITH LED GFN; Manufacturer Part New SchematicLib; LCSC Part # C354964
LED11, LED12, LED13, LED14, LED15, LED16, LED17, LED18, LED19: LED_PLCC2_5.7x3.0_Pad; LED_Yuji_5730

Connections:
/AnodeLedJoueur1_1: BoutonLedJ1_1.5 (A), LED11.2 (A); also elsewhere on the board
/AnodeLedJoueur1_2: BoutonLedJ1_2.5 (A), LED12.2 (A); also elsewhere on the board
/AnodeLedJoueur1_3: BoutonLedJ1_3.5 (A), LED13.2 (A); also elsewhere on the board
/AnodeLedJoueur1_4: BoutonLedJ1_4.5 (A), LED14.2 (A); also elsewhere on the board
/AnodeLedJoueur1_5: BoutonLedJ1_5.5 (A), LED15.2 (A); also elsewhere on the board
/AnodeLedJoueur1_6: BoutonLedJ1_6.5 (A), LED16.2 (A); also elsewhere on the board
/AnodeLedJoueur1_7: BoutonLedJ1_7.5 (A), LED17.2 (A); also elsewhere on the board
/AnodeLedJoueur1_8: BoutonLedJ1_8.5 (A), LED18.2 (A); also elsewhere on the board
/AnodeLedJoueur1_9: BoutonLedJ1_9.5 (A), LED19.2 (A); also elsewhere on the board
/Bouton J1_1: BoutonLedJ1_1.3, BoutonLedJ1_1.4; also elsewhere on the board
/Bouton J1_2: BoutonLedJ1_2.3, BoutonLedJ1_2.4; also elsewhere on the board
/Bouton J1_3: BoutonLedJ1_3.3, BoutonLedJ1_3.4; also elsewhere on the board
/Bouton J1_4: BoutonLedJ1_4.3, BoutonLedJ1_4.4; also elsewhere on the board
/Bouton J1_5: BoutonLedJ1_5.3, BoutonLedJ1_5.4; also elsewhere on the board
/Bouton J1_6: BoutonLedJ1_6.3, BoutonLedJ1_6.4; also elsewhere on the board
/Bouton J1_7: BoutonLedJ1_7.3, BoutonLedJ1_7.4; also elsewhere on the board
/Bouton J1_8: BoutonLedJ1_8.3, BoutonLedJ1_8.4; also elsewhere on the board
/Bouton J1_9: BoutonLedJ1_9.3, BoutonLedJ1_9.4; also elsewhere on the board
/Groupe bouton led J1/Vcc Bouton J1: BoutonLedJ1_1.1, BoutonLedJ1_1.2, BoutonLedJ1_2.1, BoutonLedJ1_2.2, BoutonLedJ1_3.1, BoutonLedJ1_3.2, BoutonLedJ1_4.1, BoutonLedJ1_4.2, BoutonLedJ1_5.1, BoutonLedJ1_5.2, BoutonLedJ1_6.1, BoutonLedJ1_6.2, BoutonLedJ1_7.1, BoutonLedJ1_7.2, BoutonLedJ1_8.1, BoutonLedJ1_8.2, BoutonLedJ1_9.1, BoutonLedJ1_9.2; also elsewhere on the board
COM7: BoutonLedJ1_1.6 (C), BoutonLedJ1_2.6 (C), BoutonLedJ1_3.6 (C), BoutonLedJ1_4.6 (C), BoutonLedJ1_5.6 (C), BoutonLedJ1_6.6 (C), BoutonLedJ1_7.6 (C), BoutonLedJ1_8.6 (C), BoutonLedJ1_9.6 (C), LED11.1 (K), LED12.1 (K), LED13.1 (K), LED14.1 (K), LED15.1 (K), LED16.1 (K), LED17.1 (K), LED18.1 (K), LED19.1 (K); also elsewhere on the board

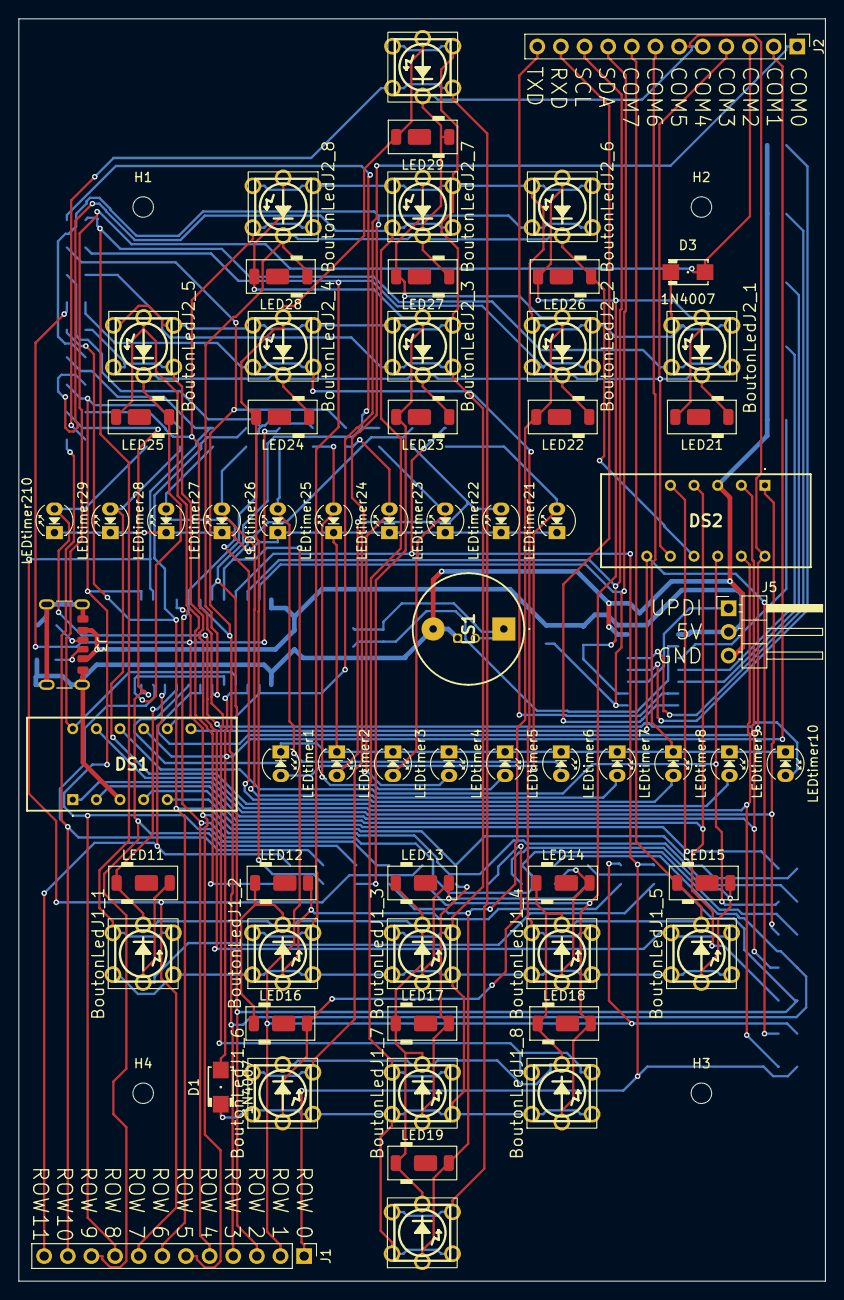
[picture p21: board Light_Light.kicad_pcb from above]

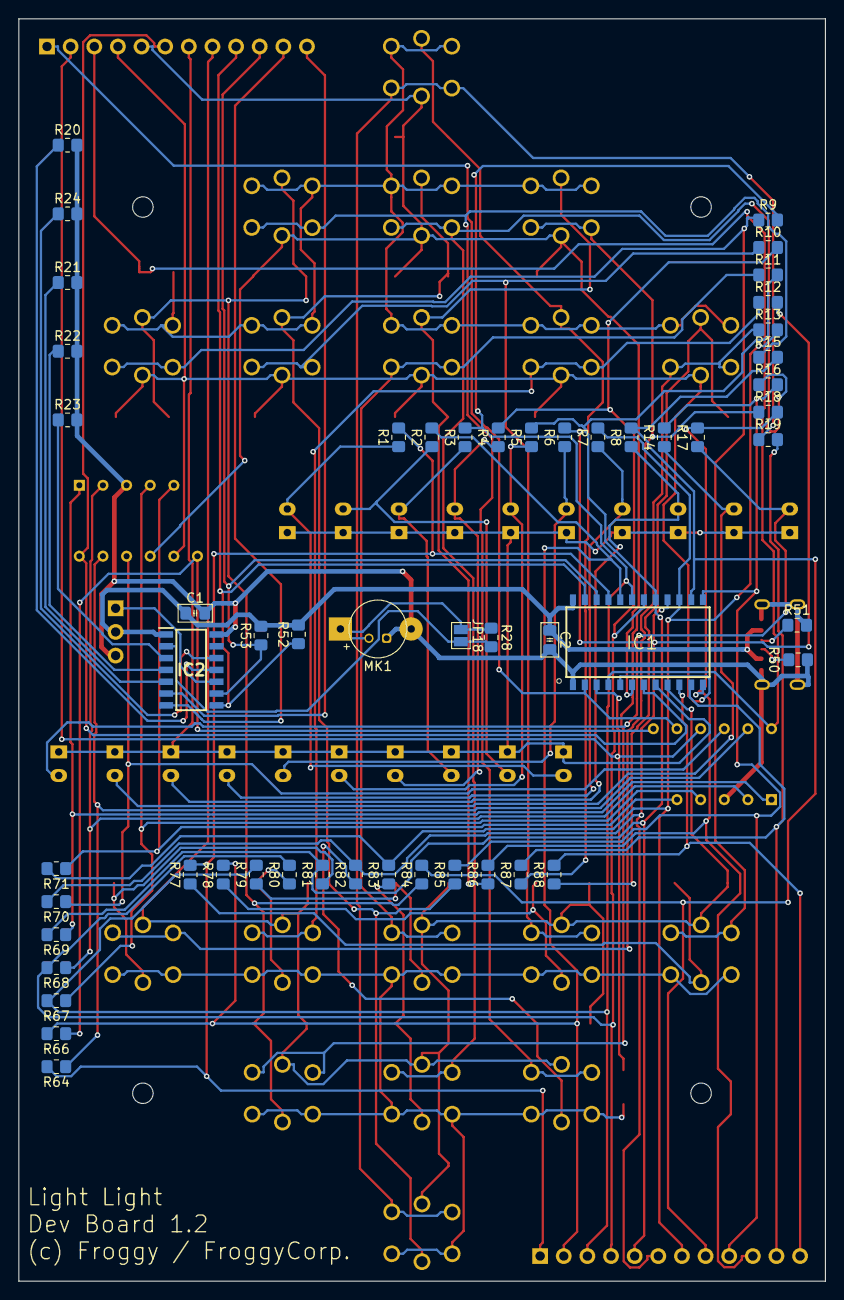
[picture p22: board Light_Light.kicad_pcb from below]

Board: 2 copper layers, 86.7 x 135.7 mm, 123 parts (54 on the bottom side), 76 nets.

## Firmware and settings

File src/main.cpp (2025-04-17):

//Copyright (c) 2025 Froggy / FroggyCorp.
//Do what you want with it until it's not money

#include "main.h"

void setup()
{
  Wire.begin();
  Serial.begin(115200); 
  while (!Serial);

  randomSeed(analogRead(0));
  HT16K33_init();

  //on efface les scores lors du premier lancement
  if (EEPROM.read(100) != 123) {
    EEPROM.write(100, 123);
    write_highscore(0, 1);
    write_highscore(0, 2);
  }
}


void loop()
{
    uint8_t numero_jeu = 0;
    numero_jeu = animation_debut();
    animation_lancement_jeu();
    if (numero_jeu == 1)
      jeu_1();
    else if(numero_jeu == 2)
      jeu_2();
    animation_gagnant(numero_jeu);

    clear_affichage();
    delay(2000);
}

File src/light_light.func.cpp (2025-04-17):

//Copyright (c) 2025 Froggy / FroggyCorp.
//Do what you want with it until it's not money

#include "light_light.func.h"
#include "ascii_led.h"
#include "sound.h"

uint8_t array_led_score[6];
uint16_t array_led_joueur[2];
uint16_t array_led_timer = 0;
uint16_t array_bouton[2];
uint16_t score[2];
bool bool_update_affichage = 0;
#if EEPROM_SAVE_SOUND == 1
bool bool_music_on = EEPROM.read(EEPROM_CONF_SOUND);
#else
bool bool_music_on = 1;
#endif
uint32_t timer_tricking_external_battery = 0;
uint8_t state_tricking_external_battery = LOW;

void animation_lancement_jeu() {
    clear_affichage();
    update_affichage(true);
    noTone(pin_musique);

    uint32_t millis_animation = millis();
    const uint32_t tick = 10;    //definit un tick de la boucle en mS

    uint8_t tick_animation_led_timer = 0;
    uint8_t index_animation_led_timer = 0;

    while (true) {
        if (millis() - millis_animation > tick) {
            millis_animation = millis();
            tick_animation_led_timer ++;
        }

        if (tick_animation_led_timer == 50) {
            tick_animation_led_timer = 0;

            if (index_animation_led_timer == 0) {
                array_led_timer = 0b1111111111;
                if (bool_music_on)
                    tone(pin_musique, 500);
            }
            if (index_animation_led_timer == 2) {
                array_led_timer = 0b11111;
                if (bool_music_on)
                    tone(pin_musique, 500);
            }
            if (index_animation_led_timer == 4) {
                array_led_timer = 0b11;
                if (bool_music_on)
                    tone(pin_musique, 500);
            }
            if ((index_animation_led_timer == 1) || (index_animation_led_timer == 3) || (index_animation_led_timer == 5)) {
                array_led_timer = 0;
                if (bool_music_on)
                    noTone(pin_musique);
            }
            
            if ((index_animation_led_timer == 6) || (index_animation_led_timer == 7))
                if (bool_music_on)
                    tone(pin_musique, 1000);
            index_animation_led_timer++;

            update_affichage(true);
        }

        if (index_animation_led_timer == 8)
            return;

        tricking_external_battery();
    }


}

uint8_t animation_debut() {
    clear_affichage();
    update_affichage(true);
    noTone(pin_musique);

    uint32_t millis_animation = millis();
    const uint32_t tick = 20;    //definit un tick de la boucle en mS

    uint8_t tick_read_bouton = 0;
    uint32_t tick_read_bouton_2 = 0;


    uint8_t tick_animation_led_joueur = 0;
    uint8_t count_animation_led_joueur = 0;

    uint8_t tick_animation_led_timer = 0;
    int8_t part_animation_led_timer = -1;
    int16_t numero_bit_animation_led_timer;
    int8_t direction_animation_led_timer;
    uint16_t tmp_array_led_timer; 

    uint8_t tick_animation_led_score = 0;
    uint8_t index_animation_led_score = 0;

    uint8_t tick_animation_son = 0;
    uint8_t index_animation_son = 0;
    uint32_t timer_changement_bool_musique_on = 0;

    while (true) {  //~3ms / boucle sur UNO
        if (millis() - millis_animation > tick) {
            millis_animation = millis();
            tick_animation_led_joueur ++;
            tick_animation_led_timer ++;
            tick_animation_led_score ++;
            tick_animation_son ++;
            tick_read_bouton ++;
            tick_read_bouton_2 ++;
        }

        //scrolling led score
        if (tick_animation_led_score == 10) {
            tick_animation_led_score = 0;
            index_animation_led_score = affichage_texte(index_animation_led_score, texte_animation_debut, 0);
            array_led_score[3] = array_led_score[0];
            array_led_score[4] = array_led_score[1];
            array_led_score[5] = array_led_score[2];
        }

        //animation led timer
        if (tick_animation_led_timer == 3) {
            tick_animation_led_timer = 0;

            if (part_animation_led_timer == -1) {//initialisation
                numero_bit_animation_led_timer = 0;
                direction_animation_led_timer = 1;
                tmp_array_led_timer = 0b100000000001;   //permet de définir les extremités
                part_animation_led_timer = 0;
                array_led_timer = 0;
            }

            if (part_animation_led_timer == 0) {
                if ((!bitRead(tmp_array_led_timer, numero_bit_animation_led_timer + direction_animation_led_timer)) && (numero_bit_animation_led_timer != 0))
                    bitClear(tmp_array_led_timer, numero_bit_animation_led_timer);

                numero_bit_animation_led_timer = numero_bit_animation_led_timer + direction_animation_led_timer;
                if (bitRead(tmp_array_led_timer, numero_bit_animation_led_timer)) {
                    direction_animation_led_timer = direction_animation_led_timer * -1;
                    numero_bit_animation_led_timer = numero_bit_animation_led_timer + 2*direction_animation_led_timer;
                }
                bitSet(tmp_array_led_timer, numero_bit_animation_led_timer);
                array_led_timer = tmp_array_led_timer >> 1;

                if (array_led_timer == 0b11111111111) {
                    part_animation_led_timer++;
                    direction_animation_led_timer = -1;
                    numero_bit_animation_led_timer = 10;
                }
            }
            else if (part_animation_led_timer == 1) {
                bitClear(array_led_timer, numero_bit_animation_led_timer);
                if (numero_bit_animation_led_timer == 0) {
                    numero_bit_animation_led_timer = 0;
                    part_animation_led_timer = 2;
                }
                else
                    numero_bit_animation_led_timer = numero_bit_animation_led_timer - 1;
            }
            else if (part_animation_led_timer == 2) {
                bitSet(array_led_timer, numero_bit_animation_led_timer);
                if (numero_bit_animation_led_timer == 9) {
                    numero_bit_animation_led_timer = 9;
                    part_animation_led_timer = 3;
                }
                else
                    numero_bit_animation_led_timer = numero_bit_animation_led_timer + 1;
            }
            else if (part_animation_led_timer == 3) {
                bitClear(array_led_timer, numero_bit_animation_led_timer);
                if (numero_bit_animation_led_timer == 0) {
                    part_animation_led_timer = -1;
                }
                else
                    numero_bit_animation_led_timer = numero_bit_animation_led_timer - 1;
            }
        }

        //animation led_joueurs
        if (tick_animation_led_joueur == 12) {
            tick_animation_led_joueur = 0;
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
